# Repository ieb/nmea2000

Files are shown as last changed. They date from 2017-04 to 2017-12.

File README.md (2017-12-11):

This repository contains a number of utilities generally aimed at interfacing with a NMEA2000 CAN bus and collecting stats in InfluxDB for analysis in Grafana.

The repository is mainly to keep a record of work in progress, rather than a neat and tidy implementation, but if it helps others, great.

The code runs on an Arduino Due with a CAN bus trancever.
Some code may also run on an Arduino Mega to simulate Raymarine wind, speed and temperature sensors.
The heavy lifting on the Arduino as been done by https://github.com/ttlappalainen/NMEA2000.git to use the code here on a Due you may also need
https://github.com/collin80/due_can.git https://github.com/ttlappalainen/NMEA2000_due.git which the NMEA2000 implementation and CAN Bus drivers for the Due. 

* libs contains c++ code for the ArduinoDue
** batteryMonitor.h - monitoring batteries and current using Hall Effect sensors on ADC pins.
** boarMonitor.h - emitting boat speed, wind speed data as NMEA2000 PGNs
** enviroMonitor.h - monitoring pressure and temperature
** events.h - an event queue.
** monitors.h - constants
** motionSensor.h - rotation, acceleration sensor
** multiSensor.h - wind and water speed sensor with corrections for motion etc, also calculates 
** pogo1250.h - Data for a pogo1250 polar.
** polar.h - polar performance calculations.
** statistics.h - stats for linear and radial data.
** testmocks.h - mocks to allow tests to run.
** waterMonitor.h - water temp sensor.
* monitorAndBridge contains a sensor monitor and bridge from a NMEA2000 bus to ActisenseSerial, with the ability to read the raw signals from Airmar water speed and RayMarine WindSensorts, battery voltages and a 10DoF sensor board. There is a built in polar performance monitor that emits % polar performance and target boat speed.

The Marine instrument installation is a Raymarine SeatalkNG installation with a e7 MFD, althogh there is nothing here that is specific to Raymarine. At the electrical and protocol level SeatalkNG == NMEA2000 == CAN@250kb/s. The differences are physical, mainly to ease installation.

As well as emitting CAM messages onto the NMEA2000 bus the Arduino Due runs code to implement sufficient of the Actisense protocol to feed SignalK running on a Pi Zero W. Installation of that part is listed below. Most of this is achieved with confgiguration and no additional code.

# Pi Zero W installation - Rough notes.

Installation on a Pi Zero W for pushing stats from NMEA2000 -> Arduino Due -> SkignalK -> InfluxDB -> Grafana

Using Raspbain Lite written to a SDMicro card boot and configure the Pi Zero W, once booted. At the console (HDMI+USB Keyboard)

## Setup wifi as root
    
    cat << EOF > /etc/wpa_supplicant/wpa_supplicant.conf 
    country=GB
    ctrl_interface=DIR=/var/run/wpa_supplicant GROUP=netdev
    update_config=1
    network={
         ssid="yourSSID"
         psk="*********"
    }
    EOF

## TODO: setup as a Access Point, assuming it can be done, if not make the MFD the access point and join that network.

## Enable SSH

    raspi-config
    # then enable ssh server

## reboot to get the wifi up.

Now switch to using ssh in from a Linux box.

## install signalK requirements all as root

    apt-get update
    apt-get install -y curl git build-essential libnss-mdns avahi-utils libavahi-compat-libdnssd-dev
    cd /opt/
//    wget https://nodejs.org/dist/v6.10.2/node-v6.10.2-linux-armv6l.tar.xz
    wget https://nodejs.org/dist/v6.11.1/node-v6.11.1-linux-armv6l.tar.gz 
    tar xvzf node-v6.11.1-linux-armv6l.tar.gz  
    rm node-v6.11.1-linux-armv6l.tar.gz 
    cd /usr/local/bin/
    ln -s /opt/node-v6.11.1-linux-armv6l/bin/* .

## Install InfluxDB as root
    cd 
    wget http://ftp.us.debian.org/debian/pool/main/i/influxdb/influxdb_1.1.1+dfsg1-4_armhf.deb
    wget http://ftp.us.debian.org/debian/pool/main/i/influxdb/influxdb-client_1.1.1+dfsg1-4_armhf.deb
    dpkg -i influxdb_1.1.1+dfsg1-4_armhf.deb
    dpkg -i influxdb-client_1.1.1+dfsg1-4_armhf.deb
    apt-get install -f

## Install Grafana as root

    wget https://bintray.com/fg2it/deb-rpi-1b/download_file?file_path=main%2Fg%2Fgrafana_4.2.0_armhf.deb
    mv download_file\?file_path\=main%2Fg%2Fgrafana_4.2.0_armhf.deb grafana_4.2.0_armhf.deb
    dpkg -i grafana_4.2.0_armhf.deb 
    systemctl daemon-reload
    systemctl enable grafana-server
    systemctl start grafana-server

## Install collectd to get stats on the OS into InfluxDB

This will allow you to see if the Pi Zero is overloaded. 

    apt-get install collectd

Edit collectd to disable rrdtool, battery and irq plugins, removing the config sections.
Enable network and add the following

    <Plugin network>
          Server "127.0.0.1" "8096"
    </Plugin>

Edit /etc/influxdb/influxdb.conf to enable collectd

    [[collectd]]
      enabled = true
      bind-address = ":8096"
      database = "collectd"
      typesdb = "/usr/share/collectd/types.db"

Check that /usr/share/collectd/types.db exists  (if not its at https://github.com/collectd/collectd/blob/master/src/types.db)

    service influxdb restart
    service collectd restart

Check all is Ok

    service influxdb status
    service collectd status
    service grafana-server status

## Complete SignalK installation

As a normal user who is a member of the staff group

    cd /usr/local/src
    git clone https://github.com/SignalK/signalk-server-node.git
    cd signalk-server-node
    npm install     # Wait for some time as everything gets installed.
    npm install mdns
    sudo bash rpi-setup.sh

use port 80 to run SignalK see https://github.com/SignalK/signalk-server-node/blob/master/raspberry_pi_installation.md for more detailed info

## Add reporting to InfluxDB

    cd /usr/local/src/signalk-server-node
    npm install https://github.com/sbender9/signalk-to-influxdb
    service signalk restart

check all ok 

    service signalk status 

Then go to http://localhost and configure the influxDB plugn

check all ok again

    service signalk status 

OS level info should now be in the collectd db, create a Grafana datasource pointing to that DB.
See OS Dashboard.json and windDashboard.json for exmaples.

The SignalK process will report to InfluxDB over the http API, which involves 1 POST oepration per report.
This is probably less overhead than reporting using the InfluxDB UDP route, but keep an eye on load average
and IO stats in Grafana (see OSDashboard.json for a Grafana Daskboard on the OS). Also see WindDashboard for 
a Dashboard on AWA etc.

## Connections

The Arduino is connected to the Pi using a USB Cable, the Arduino appears as a USB CDC Serial port at /dev/ttyACM0 which can be opened at 115200 baud. 

lsusb should show

    root@lunacore:/usr/local/src/signalk-server-node# lsusb
    Bus 001 Device 005: ID 2341:003d Arduino SA 
    Bus 001 Device 001: ID 1d6b:0002 Linux Foundation 2.0 root hub
    root@lunacore:/usr/local/src/signalk-server-node# 
    root@lunacore:/usr/local/src/signalk-server-node# usb-devices 

    T:  Bus=01 Lev=00 Prnt=00 Port=00 Cnt=00 Dev#=  1 Spd=480 MxCh= 1
    D:  Ver= 2.00 Cls=09(hub  ) Sub=00 Prot=01 MxPS=64 #Cfgs=  1
    P:  Vendor=1d6b ProdID=0002 Rev=04.04
    S:  Manufacturer=Linux 4.4.50+ dwc_otg_hcd
    S:  Product=DWC OTG Controller
    S:  SerialNumber=20980000.usb
    C:  #Ifs= 1 Cfg#= 1 Atr=e0 MxPwr=0mA
    I:  If#= 0 Alt= 0 #EPs= 1 Cls=09(hub  ) Sub=00 Prot=00 Driver=hub

    T:  Bus=01 Lev=01 Prnt=01 Port=00 Cnt=01 Dev#=  5 Spd=12  MxCh= 0
    D:  Ver= 1.10 Cls=02(commc) Sub=00 Prot=00 MxPS= 8 #Cfgs=  1
    P:  Vendor=2341 ProdID=003d Rev=00.01
    S:  Manufacturer=Arduino (www.arduino.cc)
    S:  Product=Arduino Due Prog. Port
    S:  SerialNumber=9543334393335111B181
    C:  #Ifs= 2 Cfg#= 1 Atr=c0 MxPwr=100mA
    I:  If#= 0 Alt= 0 #EPs= 1 Cls=02(commc) Sub=02 Prot=01 Driver=cdc_acm
    I:  If#= 1 Alt= 0 #EPs= 2 Cls=0a(data ) Sub=00 Prot=00 Driver=cdc_acm
    root@lunacore:/usr/local/src/signalk-server-node# 

Signak node server should be configured with an actisense input listening to this port, and should have plugins configured to 
a) send data to InfluxDB b) NMEA0183. Currently there are only plugins for TCP connections which causes a high level of 
turnover of TCP ports, it might be better to use UDP, that that will need some coding.

It is possible to power the Pi from the ArduinoDue over USB and visa versa. The Arduino uses < 100mA, but the Pi might use a bit more when under full load. 

# Update - September 2017

Sending data to influxDB on a standard SignalK setup swamps InfluxDB making it unusable, probably as a result of the frequency of packets > 1s in some cases, and the way the standard signalk-to-influxDB plugin is written. New signalk-telemetry plugin dixes this sending data in one block, queued to be more effcient at a fixed rate.

It may be possible to run everything from the Pi using socketCan rather than using a Due. This needs MCP2515 trancevers, 12C for the 10Dof sensor. In addition 1Wire temperature sensors and a I2C RTC can be added. Potentially this reduces power consumption as 80mA isnt needed to power the Due any more. the Pi has no A2D so a SPI based chip would need to be used.

The Pi supports 2x CAN trancevers with SocketCAN.

Raspberry Pi 10Dof

The npm module https://www.npmjs.com/package/nodeimu works for several 10DOf sensors on i2C, setup only requires i2c is enabled.
The IMU Requires configuration see https://github.com/RTIMULib/RTIMULib2 which also requires Octave to be installed for full calibration.

dtparam=i2c_arm=on

Raspberry Pi RTC
Disconnected from ntp the Pi will not keep time, using a ds3231 over i2c gives acurate time once setup.

dtoverlay=i2c-rtc,ds3231
see http://raspmer.blogspot.co.uk/2015/07/how-to-use-ds3231-i2c-real-time-clock.html

Raspberry Pi 1 Wire

DS18B20 are 1 wire temperature sensors. To read on a Pi enable 1wire and connedt with a 4K7 pullup to 3.3v, where the 1 wire is the default pin 7 

Output is at cat  /sys/bus/w1/devices/<ID>/w1_slave.
Map the ID to the sensor by warming each sensor in turn.

https://www.npmjs.com/package/ds18b20 for NPM

Raspberry Pi CanBus

Investigating how to run over SocketCan

2x MCP2515 drivers with Trancevers from eBay, MUST be connected with 3.3V to 5V level shifters to avoid GPIO damage as the trancevers will run at 5V. 2 can be connected to get CAN0 and CAN1

Wiring 

    2 5V   --------------- Vdd
    1 3V3   ------> LS 3V3
    2 5V ---------> LS 5V
    9 GND --------> LS GND
    9 GND  --------------  GND
    19 MOSI ---->  LS ----> SI0 & SI1
    21 MOSO <----  LS <---- SO0 & SO1
    23 SCLK ------> LS ----> SCLK0 & SCLK1
    24 CE0 ------> LS ----> CS0
    26 CE1 ------> LS ----> CS1
    18 GPIO24 <--  LS <---- INT0
    22 xGPIO25 <--  LS <---- INT1

    dtoverlay mcp2515-can0  oscillator=8000000 interrupt=24
    dtoverlay mcp2515-can1  oscillator=8000000 interrupt=25

    root@raspb:~/can-utils# dmesg | egrep "spi|can"
    [  477.594591] mcp251x spi0.0 can0: MCP2515 successfully initialized.
    [  487.165293] mcp251x spi0.1 can1: MCP2515 successfully initialized.
    [  495.704786] can: controller area network core (rev 20120528 abi 9)
    root@raspb:~/can-utils# ifconfig can0
    can0: flags=128<NOARP>  mtu 16
            unspec 00-00-00-00-00-00-00-00-00-00-00-00-00-00-00-00  txqueuelen 10  (UNSPEC)
            RX packets 0  bytes 0 (0.0 B)
            RX errors 0  dropped 0  overruns 0  frame 0
            TX packets 0  bytes 0 (0.0 B)
            TX errors 0  dropped 0 overruns 0  carrier 0  collisions 0

    root@raspb:~/can-utils# ifconfig can1
    can1: flags=128<NOARP>  mtu 16
            unspec 00-00-00-00-00-00-00-00-00-00-00-00-00-00-00-00  txqueuelen 10  (UNSPEC)
            RX packets 0  bytes 0 (0.0 B)
            RX errors 0  dropped 0  overruns 0  frame 0
            TX packets 0  bytes 0 (0.0 B)
            TX errors 0  dropped 0 overruns 0  carrier 0  collisions 0

    root@raspb:~/can-utils# 

Install can-utils from source.

    # git clone https://github.com/linux-can/can-utils.git
    # cd can-utils
    # ./autogen.sh
    # ./configure
    # make
    # sudo make install

If initialisation reports a wiring problem, then there almost cerainly is a wiring problem.

Configure interface

    root@raspb:~/can-utils# ip link set can0 up type can bitrate 250000
    root@raspb:~/can-utils#  ip link set can1 up type can bitrate 250000

Test

    root@raspb:~/can-utils# ./candump can1 &
    [1]+ ./candump can1 &
    root@raspb:~/can-utils# ./cansend can0 001#1122334455667788
      can1  001   [8]  11 22 33 44 55 66 77 88
    root@raspb:~/can-utils# ./cansend can0 001#1122334455667788
      can1  001   [8]  11 22 33 44 55 66 77 88
    root@raspb:~/can-utils# ./cansend can0 001#1122334455667788
      can1  001   [8]  11 22 33 44 55 66 77 88
    root@raspb:~/can-utils# 

To echo all CAN1 traffic to CAN0, setup CAN1 to listen only, and setup CAN0 to have loopback enabled to anything reading CAN0 gets the CAN0 messages as well.

    root@raspb:~/can-utils# ip link set can0 up type can bitrate 250000 loopback on
    root@raspb:~/can-utils#  ip link set can1 up type can bitrate 250000 listen-only on

Then to bridge

    candump can1 -B can0

For can0 -> SK

see https://github.com/chacal/signalk-socketcan-device

------------------------------------------------------

Moved back to the Due for now as its single threaded and doesnt stop expecially with no memory allocation. Processing power is a lot less, but it does a lot less also, not having an OS. 84MHz is plenty for this usage.

Todo:
Test polar calcs - partially done.
Test Can0 - done
Test IMU and calibrate - done.
Test Cos and Sin - done
Test Pulse counters  - done
Test SD card
Test 1 Wire
Test wind and speed calcs
Test linear voltage regulator vs noise from dc-dc converter 
   Linear voltage is no nose, but too hot
   LTSpice model indicates a 10uF cap will eliminate ripple from buck converter.

Input is candump can0 pipe, output is signalk-socketcan-device.

    "pipedProviders": [{
      "id": "can0",
      "pipeElements": [
        {
          "type": "providers/execute",
          "options": {
            "command": "candump can0 | candump2analyzer | analyzer -json -si -nv"
          }
        },
        {
          "type": "providers/liner"
        },
        {
          "type": "providers/from_json"
        },
        {
          "type": "signalk-socketcan-device",
          "options": {
            "n2kAddress": 110,
            "canDevice": "can0"
          }
        },
        {
          "type": "providers/n2k-signalk"
        }
      ]
    }]

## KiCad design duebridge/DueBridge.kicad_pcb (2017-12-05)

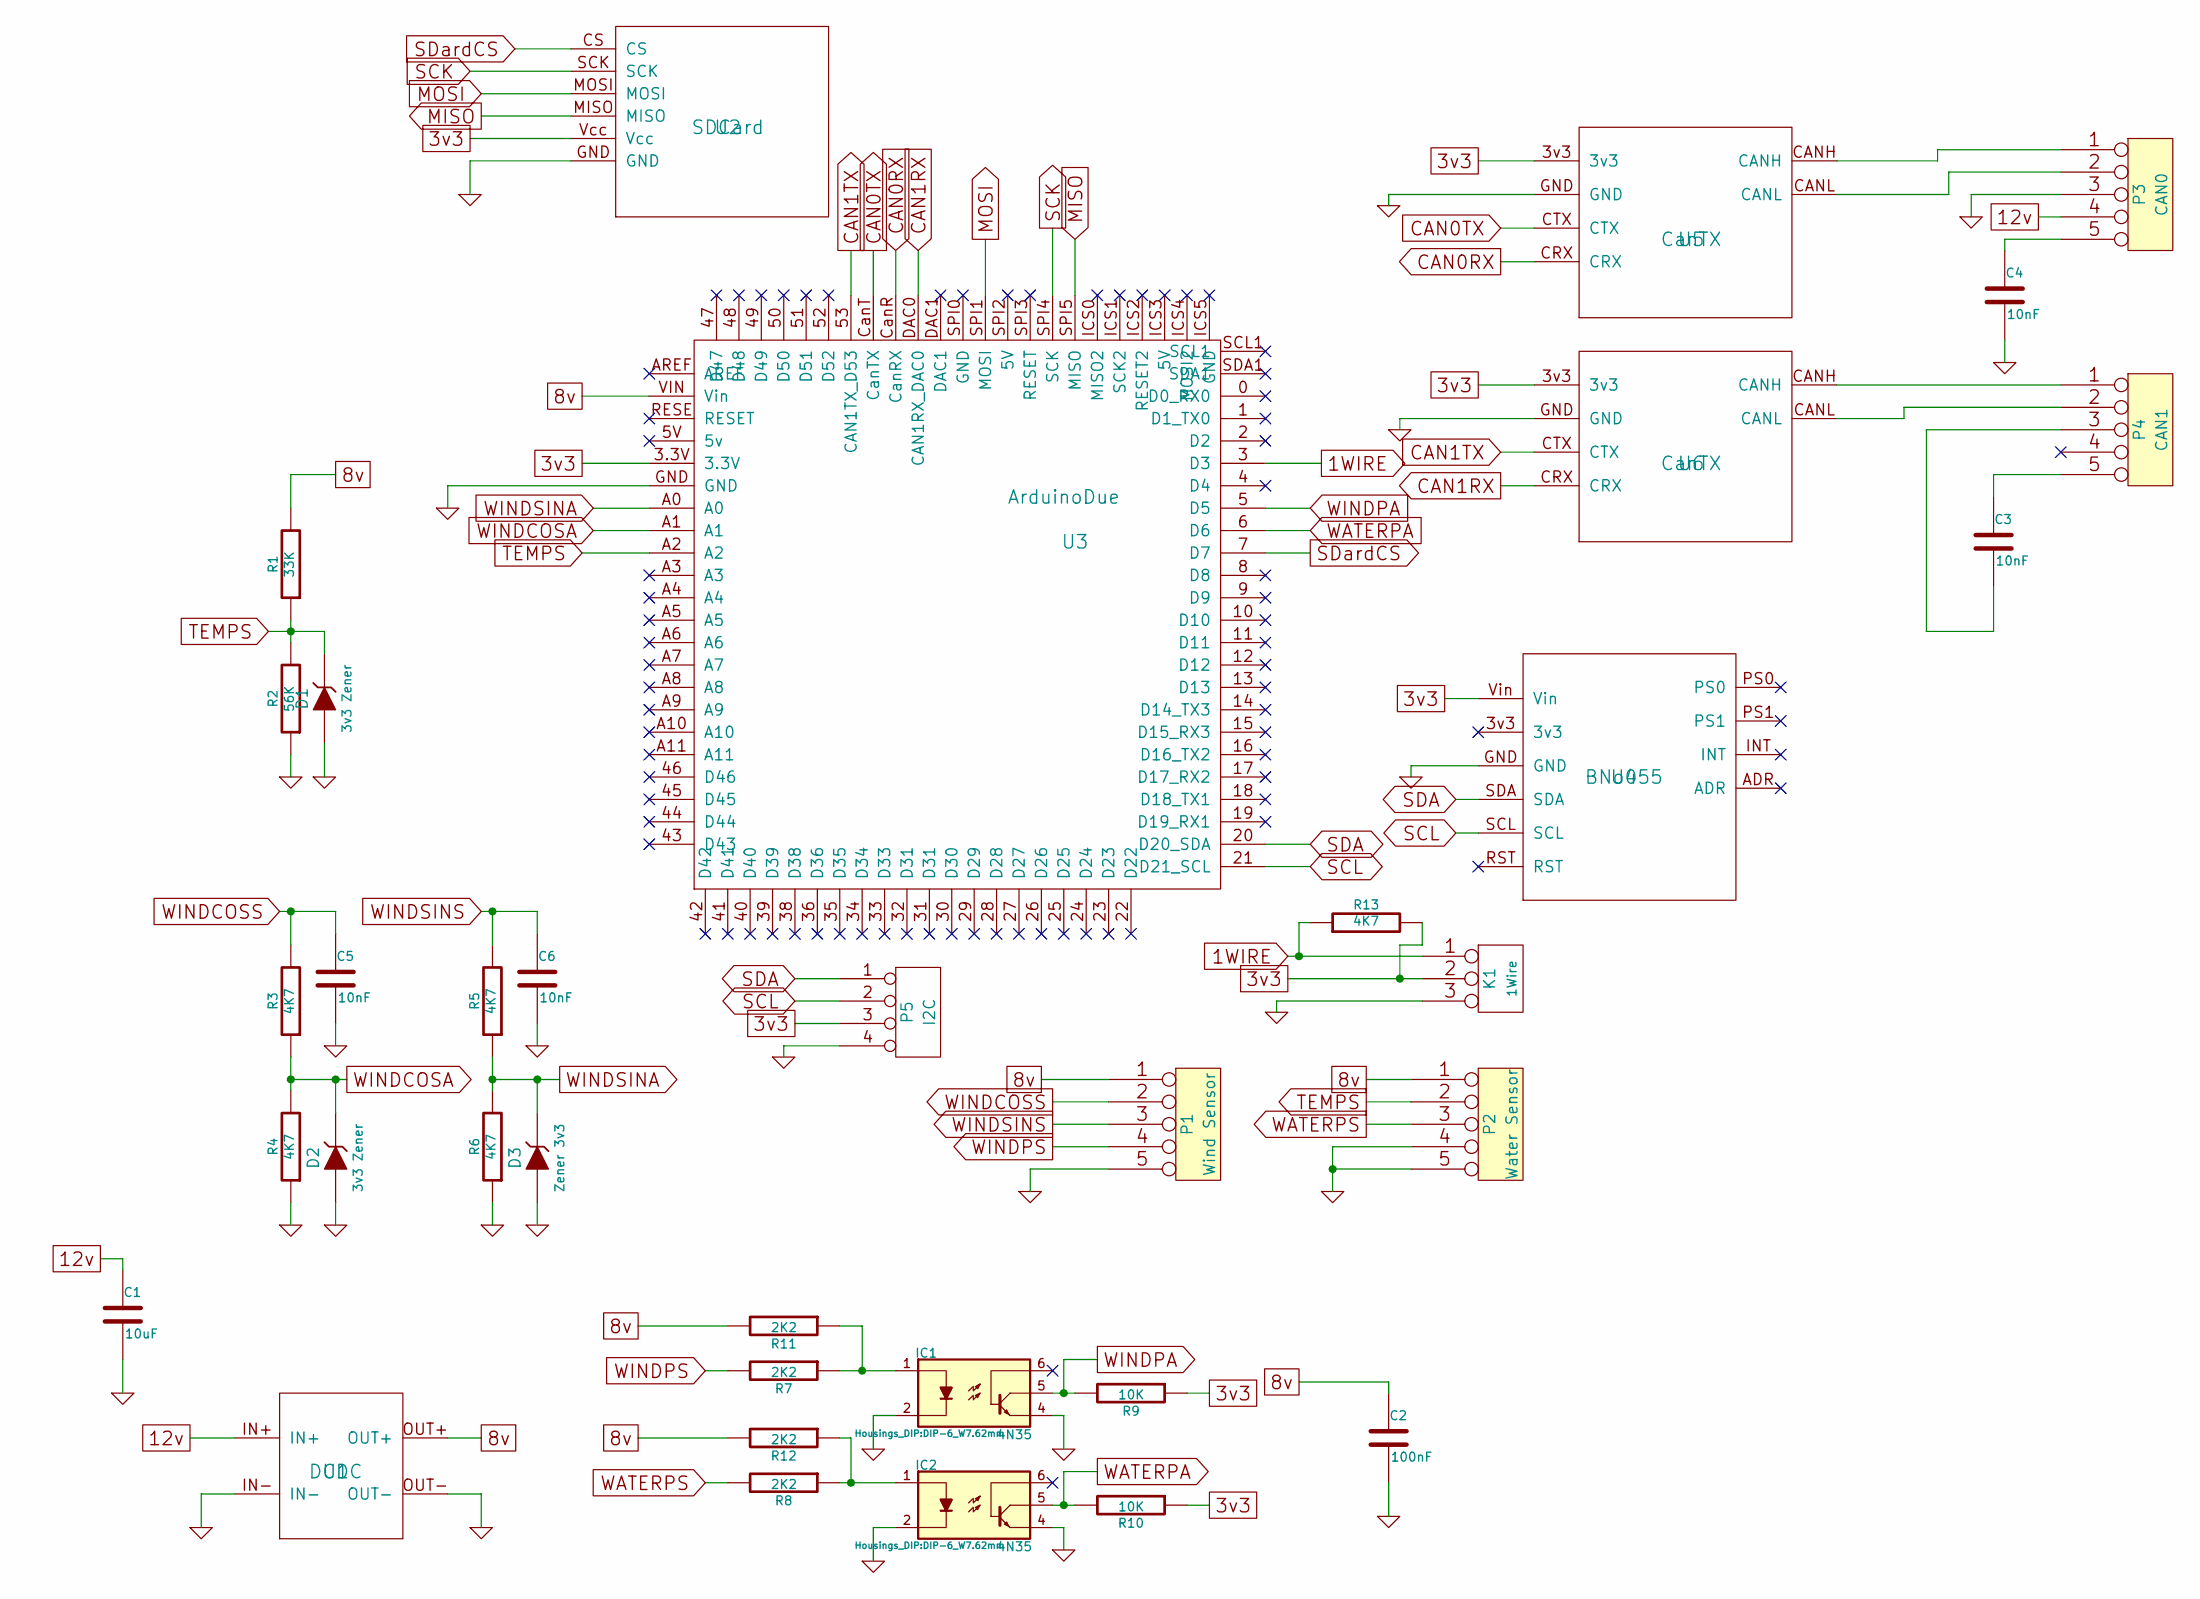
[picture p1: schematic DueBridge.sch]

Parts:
C1: 10uF; C_Radial_D10_L13_P5
C2: 100nF; C_Disc_D7.5_P5
C3, C4, C5, C6: 10nF; C_Disc_D7.5_P5
D1, D2: 3v3 Zener; Resistor_Horizontal_RM7mm
D3: Zener 3v3; Resistor_Horizontal_RM7mm
IC1, IC2: 4N35; DIP-6_W7.62mm
K1: 1Wire; Pin_Header_Straight_1x03
P1: Wind Sensor; bornier5
P2: Water Sensor; bornier5
P3: CAN0; CanCon
P4: CAN1; CanCon
P5: I2C; Pin_Header_Straight_1x04
R1: 33K; Resistor_Horizontal_RM7mm
R2: 56K; Resistor_Horizontal_RM7mm
R3, R4, R5, R6, R13: 4K7; Resistor_Horizontal_RM7mm
R7, R8, R11, R12: 2K2; Resistor_Horizontal_RM7mm
R9, R10: 10K; Resistor_Horizontal_RM7mm
U1: DCDC
U2: SDCard
U3: ArduinoDue; Arduino_Mega_Due
U4: BNo055
U5, U6: CanTX; CanTrans

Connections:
1WIRE: K1.1, R13.1, U3.3 (D3)
3v3: K1.2 (PM), P5.3, R9.1, R10.1, R13.2, U2.Vcc, U3.3.3V, U4.Vin, U5.3v3, U6.3v3
8v: C2.1, P1.1, P2.1, R1.2, R11.2, R12.2, U1.OUT+, U3.VIN (Vin)
12v: C1.1, P3.4, U1.IN+
CAN0RX: U3.CanR (CanRX), U5.CRX
CAN0TX: U3.CanT (CanTX), U5.CTX
CAN1RX: U3.DAC0 (CAN1RX_DAC0), U6.CRX
CAN1TX: U3.53 (CAN1TX_D53), U6.CTX
GND: C1.2, C2.2, C4.2, C5.2, C6.2, D1.1 (A), D2.1 (A), D3.1 (A), IC1.2, IC1.4, IC2.2, IC2.4, K1.3, P1.5, P2.4, P2.5, P3.3, P5.4, R2.1, R4.1, R6.1, U1.IN-, U1.OUT-, U2.GND, U3.GND, U4.GND, U5.GND, U6.GND
MISO: U2.MISO, U3.SPI5 (MISO)
MOSI: U2.MOSI, U3.SPI1 (MOSI)
unnamed: C3.1, P4.5
unnamed: C3.2, P4.3
unnamed: C4.1, P3.5
unnamed: IC1.1, R7.1, R11.1
unnamed: IC2.1, R8.1, R12.1
unnamed: P3.1, U5.CANH
unnamed: P3.2, U5.CANL
unnamed: P4.1, U6.CANH
unnamed: P4.2, U6.CANL
SCK: U2.SCK, U3.SPI4 (SCK)
SCL: P5.2, U3.21 (D21_SCL), U4.SCL
SDA: P5.1, U3.20 (D20_SDA), U4.SDA
SDardCS: U2.CS, U3.7 (D7)
TEMPS: D1.2 (K), P2.2, R1.1, R2.2, U3.A2
WATERPA: IC2.5, R10.2, U3.6 (D6)
WATERPS: P2.3, R8.2
WINDCOSA: D2.2 (K), R3.1, R4.2, U3.A1
WINDCOSS: C5.1, P1.2, R3.2
WINDPA: IC1.5, R9.2, U3.5 (D5)
WINDPS: P1.4, R7.2
WINDSINA: D3.2 (K), R5.1, R6.2, U3.A0
WINDSINS: C6.1, P1.3, R5.2

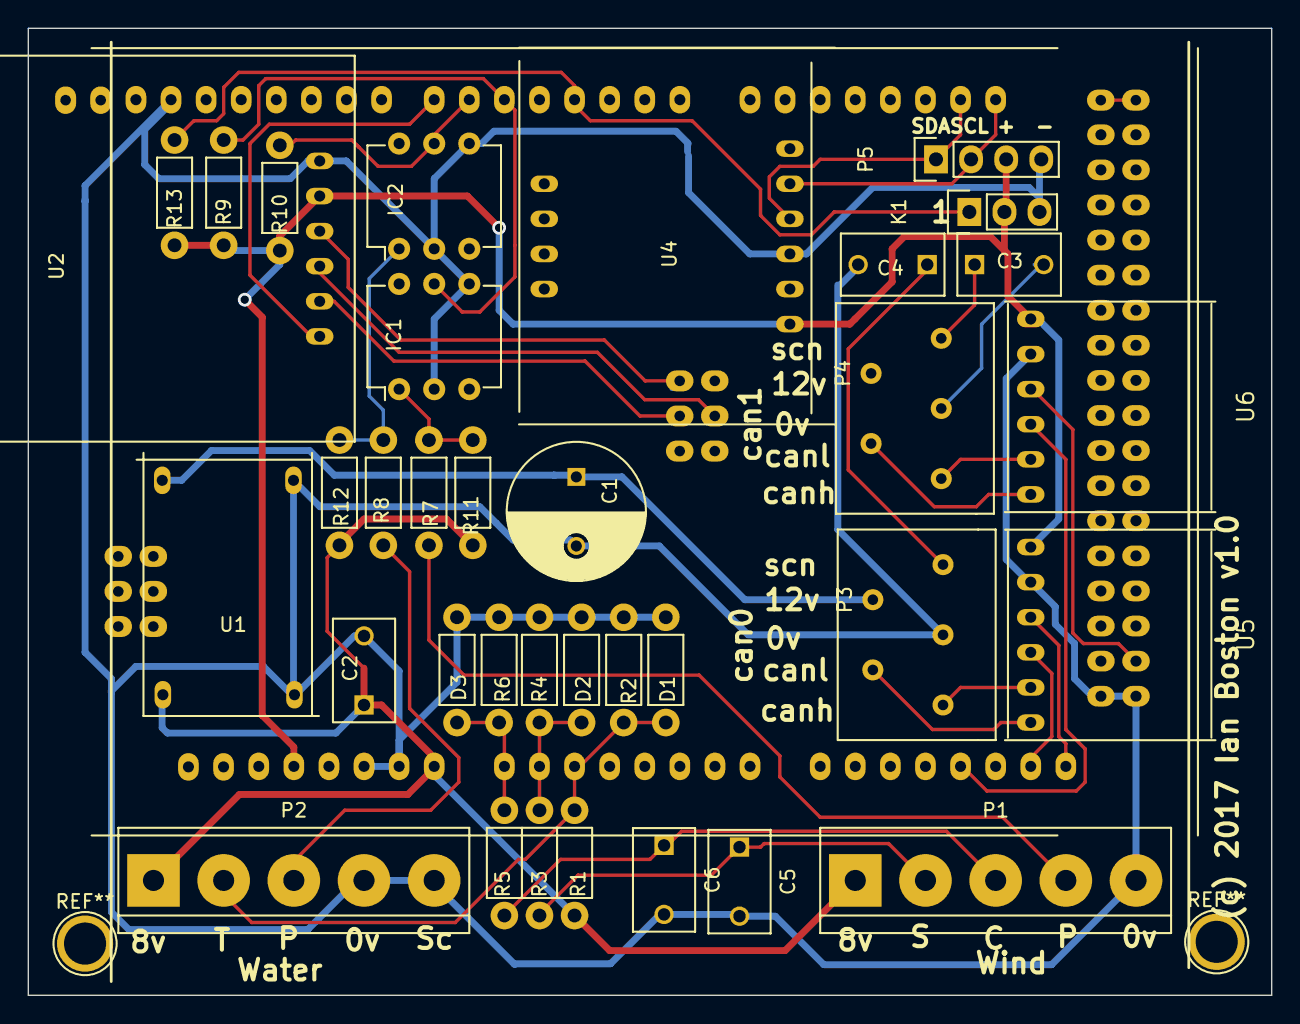
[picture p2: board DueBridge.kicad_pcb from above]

Board: 2 copper layers, 90.0 x 70.0 mm, 36 parts (0 on the bottom side), 33 nets.

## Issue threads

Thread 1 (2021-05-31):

MCP 2515 and Arduino DUE recieve

Gcaravell0, 2021-05-31:
Hi to everybody and tanks a lot for this magnific library!!
I'm replaicing my iTC-5 device with an arduino DUE. With this opportunity I also want to export some data to my PC via serial interface. I performed different communication tests with two arduino, as shown below.
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
Observing the oscilloscope I'm able to see that there is a message in the bus. I am also sure that the transimitting node is working because when I disconnect one of the two bus I see a message sending error...
However, trying to use the examples "Datadisplay 2" or "Actisense Listener" I cannot see any message on the listener node. :(
I attached the following preamble to the code:
_

```
#include <Arduino.h>
#define N2k_SPI_CS_PIN 53    // Pin for SPI select for mcp_can
#define N2k_CAN_INT_PIN 2   // Interrupt pin for mcp_can
#define USE_MCP_CAN_CLOCK_SET 8  // Uncomment this, if your mcp_can shield has 8MHz
#define USE_N2K_CAN 1 // Force mcp_can
#include <NMEA2000_CAN.h>  // This will automatically choose right CAN library and create suitable NMEA2000 object
#include <SPI.h>
#include <mcp_can.h>
#include <NMEA2000_mcp.h>
#include <N2kMessagesEnumToStr.h>
#include <N2kMaretron.h>
#include <N2kMessages.h>
#include <math.h>   // these are necessary for my code
#include <DueTimer.h>
```

_
Someone could tell me what the mistake could be?
Thank you in advance for your time and consideration

Giuseppe

ieb, 2021-06-01:
I haven't tried using the Due over SPI talking to a MCP2515 with MCP2551 transceiver. The Due has 2 Can ports built in so you don't need to use a driver (MCP2515) only a transceiver. Also It only operates at 3.3v so you cant use the MCP2515 over SPI without a level shifter to convert Due logic at 3.3v to MCP2515 at 5v.

If you do want to use the Due can ports then you will need a Can transceiver that operates at 3.3v logic but can drive the Can bus at the correct levels. Most of the 3.3v Can transceiver use a charge pump and dont interface well to most NMEA2000 buses as the other drivers on the bus tend to be 5v devices and have a higher common mode voltage. Using a MCP2562 tranciever which is a 5v device on the CAN side, but a 3.3v device on the logic side does work well. That is the setup I use. A Due using its internal Can drivers and a MCP2562 trancerver.

That said, if I was doing this again, I would connect the Pi over SPI directly to a MCP2515/MCP2551 through a level shifter and use socketCan eliminating the Due completely. See https://dayba.wordpress.com/2017/05/25/connecting-socket-can-adapter-to-signalk/   https://www.skpang.co.uk/products/pican2-can-bus-board-for-raspberry-pi-2-3?_pos=9&_sid=583288f2c&_ss=r  or you could use a cheap ebay MCP2515 driver with level shifter eg https://www.ebay.co.uk/itm/154316486567 + https://www.ebay.co.uk/itm/251742375561

If you want to replace an ITC-5, then the ESP32 modules also have 2x Can bus drivers, and are much more powerful than a Due. They will drive MCP2562 trancevers. Take a look at https://github.com/ttlappalainen/NMEA2000_esp32 for the original library and https://github.com/ieb/WindSensorBase or https://github.com/ieb/EngineMonitor for examples of code doing something similar.   The only hard part of the ITC5 will be the depth sounder which is going to need some form of high voltage ultrasonic pulse driver. The rest is ADC+pulse measurements. You might also be interested in https://github.com/SignalK/SensESP which has some of the capabilities, but doesnt interface to a CAN Bus.

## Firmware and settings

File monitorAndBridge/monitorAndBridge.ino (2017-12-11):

// Demo: NMEA2000 library. Bus listener and sender. 
//   Sends all bus data to serial in Actisense format.
//   Send all data received from serial in Actisense format to the N2kBus.
//   Use this e.g. with NMEA Simulator (see. http://www.kave.fi/Apps/index.html) to send simulated data to the bus.
// Also reads data from i2c and sends it to both the NMEA2000 network and the actisense network.

#define TRACE(x)
#define DEBUG(x)
#define INFO(x)
#define ERROR(x)


#include <Arduino.h>
#include <conversions.h>
#include <demo.h>

Stream *LogStream =  &Serial;
Stream *DataStream = &SerialUSB;

#define DUMP(x) if (Serial) { LogStream->print(F("D:")); LogStream->print(x); }
#define DUMPLN(x) if (Serial) { LogStream->print(F("D:")); LogStream->println(x); }
#define DUMPC(x) if (Serial) { LogStream->print(x); }
#define DUMPN(x) if (Serial) { LogStream->println(x); }
#define INFO(x) if (Serial) { LogStream->print(F("I:")); LogStream->print(x); }
#define INFOLN(x) if (Serial) { LogStream->print(F("I:")); LogStream->println(x); }
#define INFOC(x) if (Serial) { LogStream->print(x); }
#define INFOC2(x,m) if (Serial) { LogStream->print(x,m); }
#define INFON(x) if (Serial) { LogStream->println(x); }
#define INFON2(x,m) if (Serial) { LogStream->println(x,m); }

// CS for the SD Card
#define SDCARD_CS 7

#include <configuration.h>

demo_data_t demoData;


Configuration configuration = Configuration(LogStream, &demoData);

#define LOG(x) if (Serial && configuration.isLoggingOn()) { LogStream->print(F("L:")); LogStream->print(x); }
#define LOGLN(x) if (Serial && configuration.isLoggingOn()) { LogStream->print(F("L:")); LogStream->println(x); }
#define LOGC(x) if (Serial && configuration.isLoggingOn()) { LogStream->print(x); }
#define LOGN(x) if (Serial && configuration.isLoggingOn()) { LogStream->println(x); }
#define LOGC2(x,m) if (Serial && configuration.isLoggingOn()) { LogStream->print(x, m); }
#define LOGN2(x,m) if (Serial && configuration.isLoggingOn()) { LogStream->println(x, m); }
#define STATUS(x) if (Serial && configuration.isStatusOn()) { LogStream->print(x); }


#include <N2kMsg.h>
#include <NMEA2000_CAN.h>
#include <N2kMessages.h>
#include <polar.h>
#include <pogo1250.h>
#include <events.h>
#include <boatMonitor.h>
#include <waterMonitor.h>
#include <multiSensor.h>
#include <freemem.h>



// 2 PINS required for wind direction
#define WIND_SIN_ADC A0
#define WIND_COS_ADC A1
// 1 PIN required for water temp
#define WATER_TEMP_ADC A2

// Pulses from the Wind Speed (Check)
#define WIND_SPEED_PIN 5
// Pulses from the Wind Speed (Check)
#define WATER_SPEED_PIN 6






// ---  Example of using PROGMEM to hold Product ID.  However, doing this will prevent any updating of
//      these details outside of recompiling the program.
const tNMEA2000::tProductInformation MonitorProductInformation PROGMEM={
                                       1300,                        // N2kVersion
                                       200,                         // Manufacturer's product code
                                       "Boston NMEA2000 Performance Pod",    // Manufacturer's Model ID
                                       "1.0.0.13 (2016-09-19)",     // Manufacturer's Software version code
                                       "1.0.0.0 (2015-08-03)",      // Manufacturer's Model version
                                       "00000001",                  // Manufacturer's Model serial code
                                       0,                           // SertificationLevel
                                       1                            // LoadEquivalency
                                      };                                      

// ---  Example of using PROGMEM to hold Configuration information.  However, doing this will prevent any updating of
//      these details outside of recompiling the program.
const char ProdInfo1[] PROGMEM = "Ian Boston, ianboston@gmail.com"; // Manufacturer information
const char ProdInfo2[] PROGMEM = "Performance Pod"; // Installation description1
const char ProdInfo3[] PROGMEM = "Wind, Water, Motion, Environment, Polars"; // Installation description2




// initialise the polar chart for the boat, defined in pogo1250.h
Polar_Performance polarPerformance = Polar_Performance(POGO1250_NAME,
        POGO1250_N_TWA, 
        POGO1250_N_TWS,
        (uint16_t *)pogo1250Data_twa,
        (uint16_t *)pogo1250Data_tws,
        (uint16_t *)pogo1250Data_bsp);

// statistics collect data from monitors.
Statistics statistics = Statistics();



// The Boat monitor calcultes derived values and makes the data available to the system.
BoatMonitor boatMonitor = BoatMonitor(&polarPerformance, 
        &statistics);


/*******************************************************************

Reads pulses from both water and wind, and reads sin/cos from wind.

MultiSensor
 Statistics *statistics,
      PulseSensor *windSpeedSensor,
      PulseSensor *waterSpeedSensor,
      AngleSensor *windAngleSensor,
      IMUSensor *imuSensor,
      double Kfactor = 12,
      double mastHeight = 17.5) {
 *****************************************************************/


AngleSensor windAngleSensor = AngleSensor(WIND_SIN_ADC, WIND_COS_ADC, &demoData);
PulseSensor windSpeedSensor = PulseSensor(knotsToMs(1.045F), &readWindMonitor, &windPulseHandler, WIND_SPEED_PIN, &(demoData.windSpeed));
PulseSensor waterSpeedSensor = PulseSensor(knotsToMs(5.5F), &readWaterMonitor, &waterPulseHandler, WATER_SPEED_PIN, &(demoData.waterSpeed));
Adafruit_BNO055 bno = Adafruit_BNO055(55);
IMUSensor imuSensor = IMUSensor(&bno, &demoData);

MultiSensor multiSensor = MultiSensor( &statistics, 
        &windSpeedSensor,
        &waterSpeedSensor,
        &windAngleSensor,
        &imuSensor);


/****************************************************************

Reads a voltage representing temperature from a thermistor housed 
in the Airmar speed sensor.

*****************************************************************/

WaterMonitor waterMonitor = WaterMonitor(WATER_TEMP_ADC, &demoData);



/*********************************************************

Collectr together the messages 

**********************************************************/

const unsigned long TransmitMessages[] PROGMEM={
  MultiSensor_MESSAGES,
  BoatMonitor_MESSAGES,
  WaterMonitor_MESSAGES,
  0};



void setup() {
  pinMode(LED_BUILTIN, OUTPUT);

  Serial.begin(115200);
  
  SerialUSB.begin(115200);


  populateEventQueue();
  configuration.init();
  configuration.disableLogging();
  configuration.testPatterns();   
  configuration.disableLogging();
  updateConfig();
  polarPerformance.init();
  imuSensor.init();
  multiSensor.init();
  boatMonitor.init();
  waterMonitor.init();
  initCanBus();
}




void loop() {
  // process NMEA2000 events.
  NMEA2000.ParseMessages();

  // process configuration events.
 uint8_t r = configuration.read();
 switch(r) {
  case CONFIG_UPDATE_RUNTIME:
    updateConfig();
    break;
  case CONFIG_CURRENT_STATUS:
    dumpRunstate();
    break;
  case CONFIG_IMU_CALIBRATION:
    calibrateImu();
    break;
  }

  // process timed events.
  tickTock();
}

/**********************************************************

Initialse Can0

***********************************************************/
void initCanBus() {

  NMEA2000.SetProductInformation(&MonitorProductInformation );
  NMEA2000.SetProgmemConfigurationInformation(ProdInfo1,ProdInfo2,ProdInfo3);
  NMEA2000.SetDeviceInformation(1,      // Unique number. Use e.g. Serial number.
                                132,    // Device function=Analog to NMEA 2000 Gateway. See codes on http://www.nmea.org/Assets/20120726%20nmea%202000%20class%20&%20function%20codes%20v%202.00.pdf
                                25,     // Device class=Inter/Intranetwork Device. See codes on  http://www.nmea.org/Assets/20120726%20nmea%202000%20class%20&%20function%20codes%20v%202.00.pdf
                                2048    // Just choosen free from code list on http://www.nmea.org/Assets/20121020%20nmea%202000%20registration%20list.pdf                               
                               );

// class:60, function: 155, manufacture: 135 is Airmar speed sensor.
// class:25, function 132, manufacturer: 2048 is custom


  NMEA2000.SetForwardStream(DataStream);  // PC output on due Native USB port, the programming port is used for diag and programming.


  // make it listen and be a node, then enable forwarding to make it forward to actisense.
  // N2km_ListenOnly
  // NMEA2000.SetMode(tNMEA2000::N2km_ListenAndSend);
  // ListenAndNode makes the device listen to inbound messages and act as a device announcing itself to the bus.
  // Provided the trancever is working correctly in this mode the device will appear on a Raymarine e7 when scanning the bus for other devices.
  //

  NMEA2000.SetMode(tNMEA2000::N2km_ListenAndNode,22);
  //NMEA2000.SetMode(tNMEA2000::N2km_NodeOnly,22);
  
  // Set to true to forward messages from the N2KBus to serial.
  NMEA2000.EnableForward(true);
  NMEA2000.SetForwardSystemMessages(true);
  NMEA2000.SetForwardOwnMessages(true);
  
  // NMEA2000.SetForwardType(tNMEA2000::fwdt_Text); // Show in clear text
  
  NMEA2000.SetMsgHandler(&HandleNMEAMessage);
  NMEA2000.Open();
  
}


void HandleNMEAMessage(const tN2kMsg &N2kMsg) {
  // for the PGNs we are interested in update the statistics.
  unsigned long tnow = millis();
        int Index=0, nparams=0;
  switch(N2kMsg.PGN) {
    case 128259: // boat speed
      break;
    case 128267: // depth transducer
      break;
    case 130310: // env params
      break;
    case 128275: // distance
      break;
    case 130846: // set alarm state
      break;
    case 59904: // ISO Request(
      unsigned long RequestedPGN;
      ParseN2kPGNISORequest(N2kMsg, RequestedPGN);
      LOG(F("ISO Requested PGN "));LOGN(RequestedPGN);
      // 126996
      break;
    case 61184: // transducer setup
    case 65368: // ??
      break;
    case 126208: // NMEA Group Request FN
         LOG(F("Group FN Request  DataLen "));
         LOGC(N2kMsg.DataLen);
         LOGC(F(",FNCOde,"));
         LOGC(N2kMsg.GetByte(Index));
         LOGC(F(",Requested PGN,"));
         char b[3];
         uint32_t v;
         b[0] = N2kMsg.GetByte(Index);
         b[1] = N2kMsg.GetByte(Index);
         b[2] = N2kMsg.GetByte(Index);
         memcpy(&v, &b[0], 3);
         LOGC(v);
         LOGC(F(",Transmission Interval,"));
         LOGC(N2kMsg.Get4ByteUInt(Index));
         LOGC(F(",Transmission Interval Offset,"));
         LOGC(N2kMsg.Get2ByteUInt(Index));
         LOGC(F(",Number of Parameters,"));
         nparams = N2kMsg.GetByte(Index);
         LOGN(nparams);
         // 5 bytes left   2 and 1
         // LOG:Group FN Request  DataLen LOG:16LOG:,FNCOde,LOG:0LOG:,Requested PGN,LOG:130846LOG:,Transmission Interval,LOG:4294967295LOG:,Transmission Interval Offset,LOG:65535LOG:,Number of Parameters,2


          
          // AirMar emit 065285


//      OG:Got Message:LOG:60928
//LOG:ISO Requested PGN 60928 // address claim
//LOG:ISO Requested PGN 126996 // product info
//LOG:Got Message:LOG:127258 // magnetic variation
//LOG:Got Message:LOG:130919 // unknown
//LOG:Got Message:LOG:130919
//LOG:ISO Requested PGN 126996 // product info


      break;
    default:
      LOG(F("Got Message:"));
      LOGLN(N2kMsg.PGN);
  }

  // nothing done with inbound messages for the moment.
  // may want to process configuration messages.
}

/**
 * Airmar
 * 128267
 */

void calibrateImu() {
  if ( imuSensor.readConfiguration(&configuration) ) {
    INFOLN("IMU Sensor Calibration retrieved");
  } else {
    INFOLN("IMU Sensor Calibration not complete.");
  }
}

void updateConfig() {
  imuSensor.updateConfiguration(&configuration);
  multiSensor.updateConfiguration(&configuration);
  boatMonitor.updateConfiguration(&configuration);
  waterMonitor.updateConfiguration(&configuration);
}

void dumpRunstate() {
  imuSensor.dumpRunstate();
  multiSensor.dumpRunstate();
  boatMonitor.dumpRunstate();
  waterMonitor.dumpRunstate();
}


/****************************************************

Timed events. 
Handlers maintain a slot in a queue specifying when
their next event should be fired, each time their
handler is filred, the handler specifies the next time.
The loop calls ticktock() which processes the queue.

*****************************************************/

#define EnviroUpdatePeriod 10000
#define PolarUpdatePeriod 5000


#define MULTISENSOR_READ_PERIOD 200
#define MULTISENSOR_CALC_PERIOD 500

// Sense at 10Hz
unsigned long RunMultiSensor(unsigned long now) {
  multiSensor.read();
  return now+MULTISENSOR_READ_PERIOD;
}

// Calculate and send data at 5Hz
unsigned long RunMultiSensorCalc(unsigned long now) {
  multiSensor.calculate();
  tN2kMsg N2kMsg;
  multiSensor.fillBoatSpeed(N2kMsg);
  NMEA2000.SendMsg(N2kMsg);
  multiSensor.fillAparentWind(N2kMsg);
  NMEA2000.SendMsg(N2kMsg);
  multiSensor.fillTrueWind(N2kMsg);
  NMEA2000.SendMsg(N2kMsg);
  return now+MULTISENSOR_CALC_PERIOD;
}


unsigned long  SendN2KEnviro(unsigned long now) {
  if(waterMonitor.read()) {
    LOGLN(F("Sending waterm temp"));
    tN2kMsg N2kMsg;
    waterMonitor.fillWaterTemperature(N2kMsg);
    NMEA2000.SendMsg(N2kMsg);
   }
  return millis() + EnviroUpdatePeriod;
}



unsigned long SendN2KPolar(unsigned long now) {
  if (boatMonitor.read(now) ) {
    LOGLN(F("Polar Performance"));
    tN2kMsg N2kMsg;
    boatMonitor.fillPolarPerformance(N2kMsg);
    NMEA2000.SendMsg(N2kMsg);
    boatMonitor.fillTargetBoatSpeed(N2kMsg);
    NMEA2000.SendMsg(N2kMsg);
  }
  return millis() + PolarUpdatePeriod;  
}

unsigned long LogLine(unsigned long now) {
  static uint32_t fm = 0;
  static bool blink = false;
  blink = !blink;
  digitalWrite(LED_BUILTIN, blink?HIGH:LOW);


  meminfo_t info;
  if ( freeMemory(&info) != fm ) {
    INFO(F("FreeMemory now ")); 
    INFON(info.free);
    fm = info.free; 
  } 
  if ( fm < 20000 ) {
    INFO(F("<<<<<<<<<<<<<<<<< WARNING LOW MEMORY ")); 
    INFON(info.free);
  }
  return millis() + 1000L;
}

TimedEventQueue timedEventQueue = TimedEventQueue();
EventHandler sendN2KEnviroHandler = EventHandler(&SendN2KEnviro);
EventHandler sendN2KpolarHandler = EventHandler(&SendN2KPolar);
EventHandler multiSensorHandler = EventHandler(&RunMultiSensor);
EventHandler logHandler = EventHandler(&LogLine);
EventHandler sendMultisensor = EventHandler(&RunMultiSensorCalc);

void populateEventQueue() {
  
  timedEventQueue.addHandler(&sendN2KEnviroHandler);
  timedEventQueue.addHandler(&sendN2KpolarHandler);
  timedEventQueue.addHandler(&multiSensorHandler);
  timedEventQueue.addHandler(&logHandler);
  timedEventQueue.addHandler(&sendMultisensor);

}

void tickTock() {
  timedEventQueue.tick(millis());
}

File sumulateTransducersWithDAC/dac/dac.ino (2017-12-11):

/**
 * This code simulates the standard St60+ Wind Sensor, to enable simulatio and debugging of a Raymarine i60/i60 or ITC5 setup without real
 * instruments or real enviroment.
 * The wind direction is simulated by driving 2 I2C DACs between 0 and the Arduino supply voltage. This is not exactly the 2-6V 
 * that the Raymarine wind transducer produces so if sending the voltages to a real ITC5 or Pods it will need conditioning.
 * 
 * All the parameter as controllable over the serial line. Default settings have AWS at 1.045Hz/kn and STW at 5.5Hz/Kn.
 * serial line runs at 115.2Kbaud, type help to see the command format.
 */


#include <Wire.h>
// #include "DueTimer.h"


#define AWS_PIN 4
#define STW_PIN 5
#define DAC_REGISTER 0x40
#define DACV 3F/4096.0F
#define WINDANGLE_UPDATE_PERIOD 500
#define SPEED_UPDATE_PERIOD 500

float awsHzPerKn = 1.045F;
float stwHzPerKn = 5.5F;
float targetAWA = 0.0F;
float targetAWS = 0.0F;
float targetSTW = 0.0F;
float targetFAWS = 0.0F;
float targetFSTW = 0.0F;
unsigned long noiseLevel = 0L;
unsigned long awsPeriod = 1000000;
unsigned long stwPeriod = 1000000;
unsigned long awsError = 0L;
unsigned long stwError = 0L;
float awa = 0.0F;



/*
 * Wiring.
 * Needs 2x MCP Digital pots set to generate wiper voltages between 2V and 6V. Cos Pin Select is pin 7, Sin pin select is pin 8
 * On Pin 4 there will be a 25/75 PWM output for AWS
 * On Pin 5 there will be a 25/75 PWM output for STW
 */

void setup() {
  // put your setup code here, to run once:
   Serial.begin(115200);
   Serial.println(F("Wind and speed Transducer simulator"));

  Wire.begin(); 

  pinMode(AWS_PIN, OUTPUT);
  pinMode(STW_PIN, OUTPUT);
  pinMode(LED_BUILTIN, OUTPUT);

  // Timer1.attachInterrupt(pulseAWS).setPeriod(500000).start();
  // Timer2.attachInterrupt(pulseSTW).setPeriod(500000).start();

}
/*
uint8_t awaState = 0;
void pulseAWS(void) {
  awaState = (awaState+1)&0x03;
  digitalWrite(AWS_PIN, awaState!=0);
}

uint8_t stwState = 0;
void pulseSTW(void) {
  stwState = (stwState+1)&0x03;
  digitalWrite(STW_PIN, stwState!=0);
}
*/
/*
 * Return the period in us.
 */
unsigned long getPeriod(float frequency) {
  if (frequency == 0 ) {
    return 500000;
  }  
  // no faster than 1Khz
  // no slower than 0.5Hz
  float period = 1000000/frequency;   
  return max(min(2000000,(unsigned long)period),1000);
}








void setVoltage(byte address, float voltageF) {
  byte op[3];
  op[0] = DAC_REGISTER;
  if ( voltageF > 4095.0F) {
    op[1] = (4095>>4) & 0xff;
    op[2] = (4095<<4) & 0xff;
  } else if ( voltageF < 0.0F ) {
    op[1] = 0x00;
    op[2] = 0x00;
  } else {
    uint16_t vi = (uint16_t) voltageF;
    op[1] = (vi>>4) & 0xff;
    op[2] = (vi<<4) & 0xff;
  }
  Wire.beginTransmission(address);
  Wire.write(op,3);
  Wire.endTransmission();
}

void setWindAngle() {
  static float lastAWA = 0.0F;
  if ( awa == lastAWA) {
    return;
  }
  lastAWA = awa;

  float cosADC = 2000.0F+1500.0F*cos(awa*M_PI/180.0F);
  float sinADC = 2000.0F+1500.0F*sin(awa*M_PI/180.0F);

  // sin MCP4725 on I2C at 0x62
  Serial.print("V0 ");
  Serial.print(cosADC);
  Serial.print(" ");
  Serial.print((float)cosADC*3.42F/4096.0F);
  Serial.print(" V1 ");
  Serial.print(sinADC);
  Serial.print(" ");
  Serial.println((float)sinADC*3.42F/4096.0F);
  setVoltage(0x62,cosADC);
  // cos MCP4725 on I2C at 0x62
  setVoltage(0x63,sinADC);    
}

int ncycles = 0, cawa = 0;
// these are the factory settings. There appears to be some significant non linearity
// between the angle generated and hte andle recored


void getIncommingChars() {
  static String input = "";
  
  char inChar = Serial.read();
  if(inChar == 59 || inChar == 10 || inChar == 13){
    if ( input.length() > 0 ) {
      Serial.println(" ");
      input.toLowerCase();
      if ( input.startsWith("awa,") ) {
        cawa = 0;
        targetAWA = input.substring(4).toFloat();
      } else if (input.startsWith("rnd,") ) {
        noiseLevel = input.substring(4).toInt();
      } else if (input.startsWith("cwa,") ) {
        cawa = input.substring(4).toInt();
      } else if (input.startsWith("aws,") ) {
        targetAWS = input.substring(4).toFloat();
        targetFAWS = targetAWS*awsHzPerKn;
      } else if (input.startsWith("ahz") ) {
        awsHzPerKn = input.substring(4).toFloat();
        targetFAWS = targetAWS*awsHzPerKn;
      } else if (input.startsWith("stw") ) {
        targetSTW = input.substring(4).toFloat();
        targetFSTW = targetSTW*stwHzPerKn;
      } else if (input.startsWith("bhz") ) {
        stwHzPerKn = input.substring(4).toFloat();
        targetFSTW = targetSTW*stwHzPerKn;
      } else if (input.startsWith("help")) {
        Serial.println(F("aws,<Aparent Wind speed in kn>"));
        Serial.println(F("awa,<Aparent Wind Angle in degrees>"));
        Serial.println(F("stw,<Boat Speed in Kn>"));
        Serial.println(F("ahz,<Hz per kn of AWS>"));
        Serial.println(F("bhz,<Hz per kn of STW>"));
      }
      Serial.print(F("AWA,"));
      Serial.print(targetAWA);
      Serial.print(F(",opAWA,"));
      Serial.print(awa);
      Serial.print(F(",AWS,"));
      Serial.print(targetAWS);
      Serial.print(F(",AWSHz,"));
      Serial.print(targetFAWS);
      Serial.print(F(",opAWSp,"));
      Serial.print(awsPeriod);
      Serial.print(F(",STW,"));
      Serial.print(targetSTW);
      Serial.print(F(",STWHz,"));
      Serial.print(targetFSTW);
      Serial.print(F(",opSTWp,"));
      Serial.print(stwPeriod);
      Serial.print(F(",AWSHz,"));
      Serial.print(awsHzPerKn);
      Serial.print(F(",STWHz,"));
      Serial.print(stwHzPerKn);
      Serial.print(F(",AWSuserr,"));
      Serial.print(awsError);
      Serial.print(F(",STWuserr,"));
      Serial.println(stwError);
      
      input = "";    
      Serial.print("->");        
    }
  } else {
    if (inChar > 32 && inChar < 127 && input.length() < 255 ) {
      input += (char)inChar;
    }
  }
}
void flashLED() {
  static unsigned long nextLED = 0L;
  static bool ledOn = true;
  if ( millis() > nextLED ) {
    nextLED = millis() + 5000;
    digitalWrite(LED_BUILTIN, ledOn);
    ledOn = !ledOn;
  }
}


void moveAWA() {
  static unsigned long nextAWAMove = 0L;
  if (cawa != 0 && millis() > nextAWAMove ) {
    targetAWA = targetAWA+1;
    if ( targetAWA > 180.0F ) {
      targetAWA = targetAWA-360.0F;
    }
    nextAWAMove = millis() + cawa;
  }
}

void updateAWA() {
  static unsigned long nextAWAUpdate = 0L;
  if (millis() > nextAWAUpdate ) {
    if ( noiseLevel > 0) {
      awa = targetAWA + random(-noiseLevel,+noiseLevel);
    } else {
      awa = targetAWA;
    }
    setWindAngle();
    nextAWAUpdate = millis() + WINDANGLE_UPDATE_PERIOD;
  }
}
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

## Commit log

2017-04-09 Fixed buid on monitorAndBridge
    [monitorAndBridge.ino]
2017-04-15 Added Simulation schema for reference
    [simulatedTransducers.kicad_pcb, simulatedTransducers.sch]
2017-06-10 Working version sending data to STNg network, fixed many issues with sending data.
    [batteryMonitor.h, monitorAndBridge.ino]
2017-09-05 Running version used over 08/2017, adds ability to configure over serial + some fixes
    [monitorAndBridge.ino]
2017-12-05 Moved to using a BNo055 and largely rewritten with a new board
    [DueBridge-B.Cu.gbl, DueBridge-B.Fab.gbr, DueBridge-B.Mask.gbs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]
2017-12-11 Tested pulse sensors, and basic PGN output.
    [DueBridge.sch]

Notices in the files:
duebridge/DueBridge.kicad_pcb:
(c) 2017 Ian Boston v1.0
